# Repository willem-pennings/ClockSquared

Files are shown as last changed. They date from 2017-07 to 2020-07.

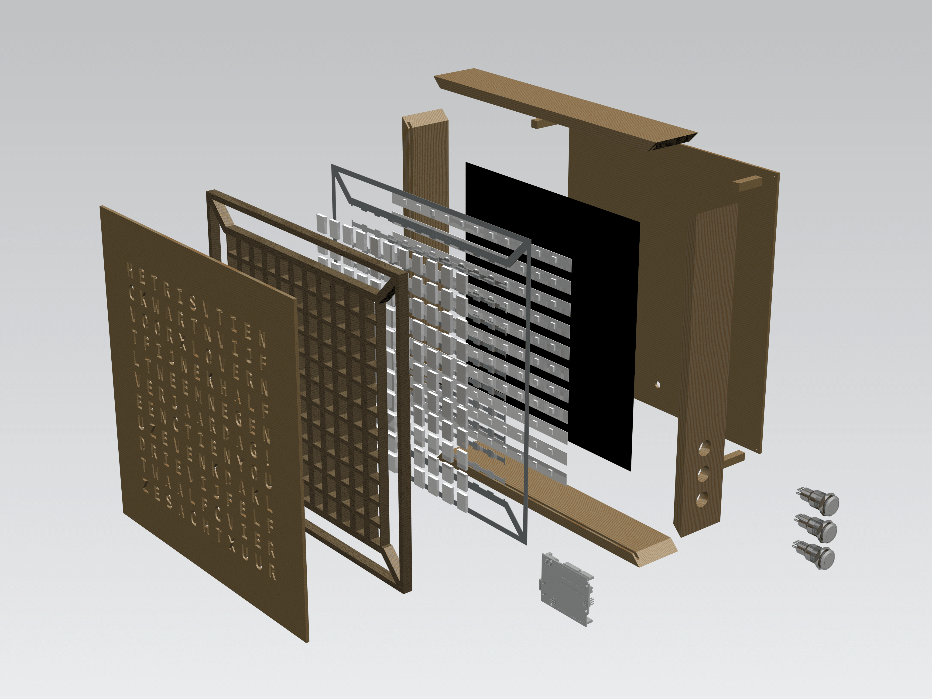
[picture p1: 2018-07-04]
assembly.png

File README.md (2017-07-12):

# Clocksquared
The Clocksquared word clock, which displays time and birthday messages

## Mechanical design files
The mechanical design files are stored inside the `Mechanical Design` folder. There's a main assembly file, `clocksquared_assy.prt`. Each of the individual components are stored in their own folder. Most files have a PDF file available with a technical drawing of the respective part.

## Source code
There are several source code files. Besides the main `wordclock.ino` file, there are other Arduino programs available for testing purposes or additional functionality (such as scrolling text).

## Other
A full build log of this clock is available at [my website](https://willemm.nl). You can also contact me through my website if you have any questions or remarks regarding this project.

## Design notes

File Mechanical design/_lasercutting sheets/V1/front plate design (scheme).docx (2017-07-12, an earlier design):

H | E | T | R | I | S | V | T | I | E | N
C | K | W | A | R | T | N | V | I | J | F
V | O | O | R | X | L | O | V | E | R | N
T | F | I | J | N | E | K | H | A | L | F
L | T | W | E | E | M | N | E | G | E | N
V | E | R | J | A | A | R | D | A | G | !
E | E | N | C | T | I | E | N | Y | O | U
B | Z | E | V | E | N | K | D | A | K | L
D | R | I | E | V | I | J | F | E | L | F
T | W | A | A | L | F | C | V | I | E | R
Z | E | S | A | C | H | T | X | U | U | R

# Word clock design (version 2.0) [Clocksquared]

- All Dutch time words (20, including “HET IS”);
- ‘Fijne verjaardag’;

Pixel number 1 (index 0) should align with top-left letter H.
Pixel number 121 (index 120) should align with bottom-right letter R.

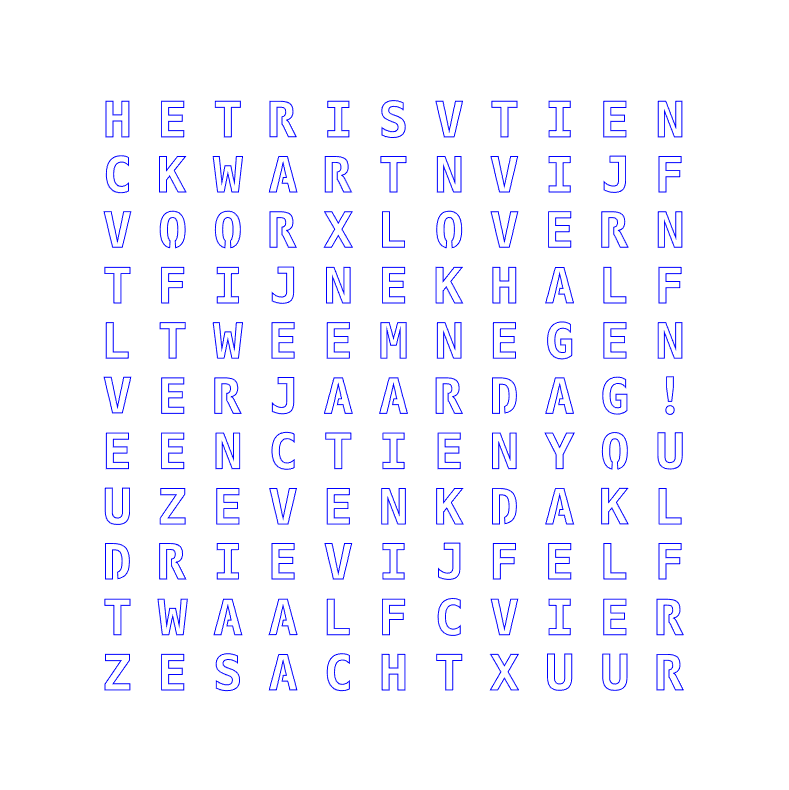
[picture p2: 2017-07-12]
letter layout - Dutch.png

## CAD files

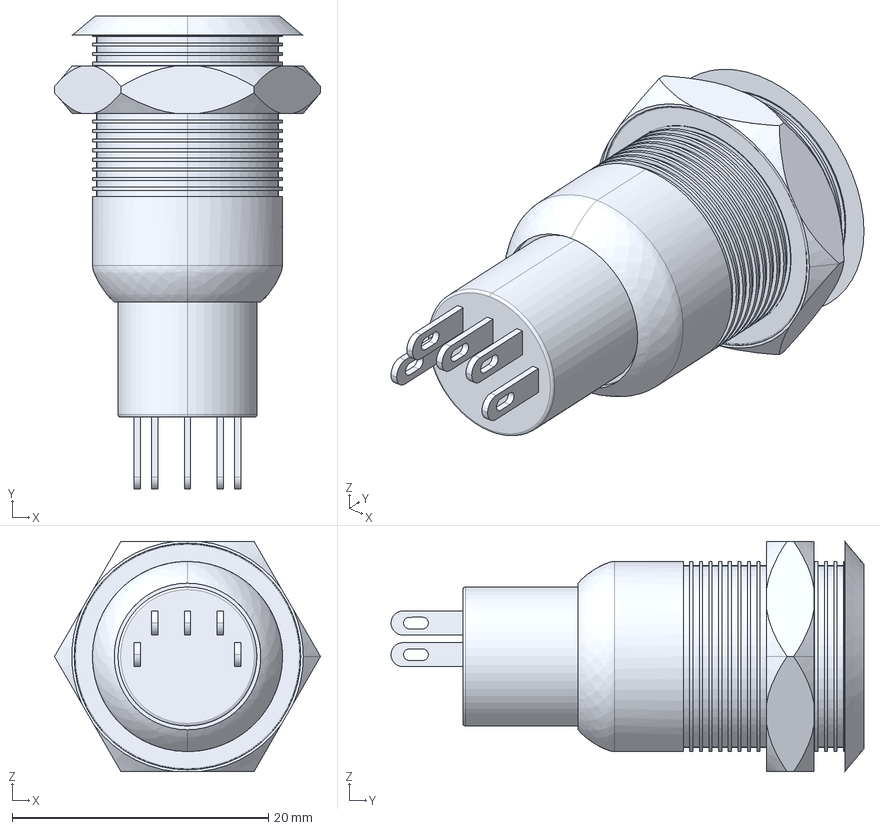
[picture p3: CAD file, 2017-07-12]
Mechanical design/components/pushbutton_16mm.stp
20.8 x 36.9 x 18.0 mm

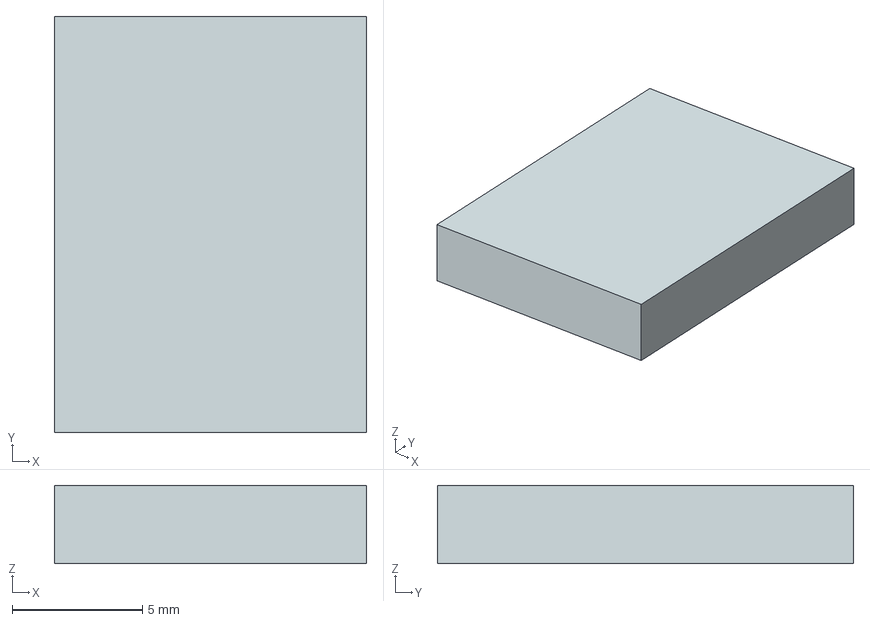
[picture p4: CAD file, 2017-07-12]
Mechanical design/diffuser/diffuser.stp
12.0 x 16.0 x 3.00 mm

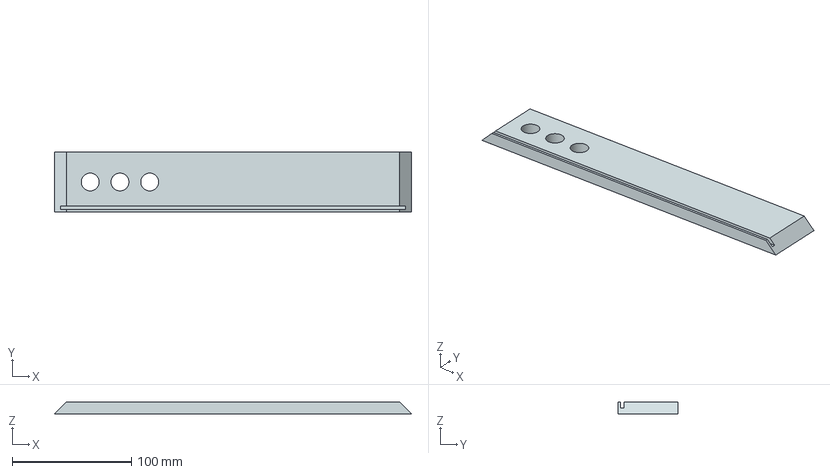
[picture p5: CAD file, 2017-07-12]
Mechanical design/frame_buttons/frame_buttons.stp
300.0 x 50.0 x 10.0 mm

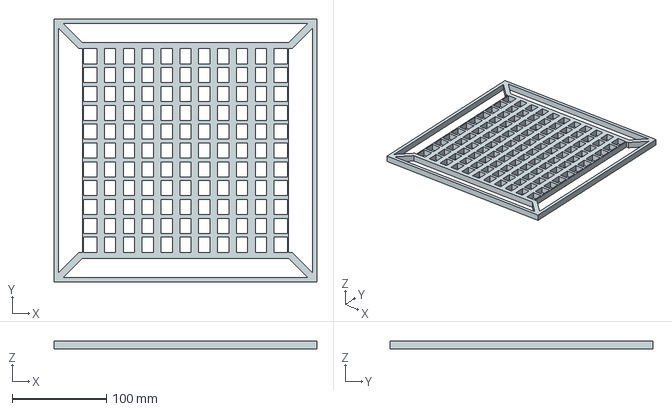
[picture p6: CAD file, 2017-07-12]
Mechanical design/grid/grid.stp
279.0 x 279.0 x 9.00 mm

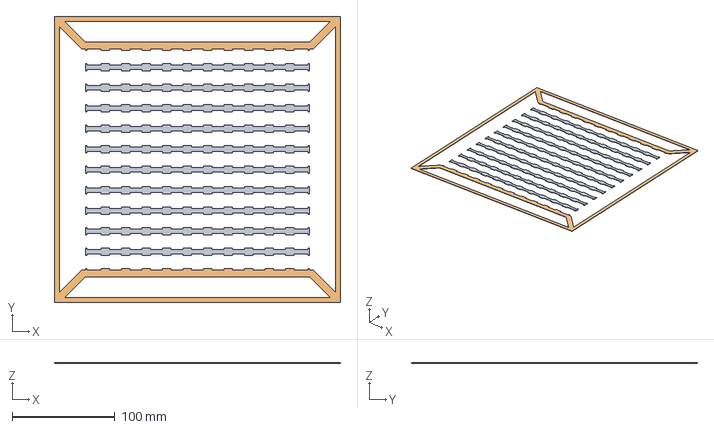
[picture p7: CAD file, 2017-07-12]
Mechanical design/grid_spacer/grid_spacer.stp
279.0 x 279.0 x 0.5 mm

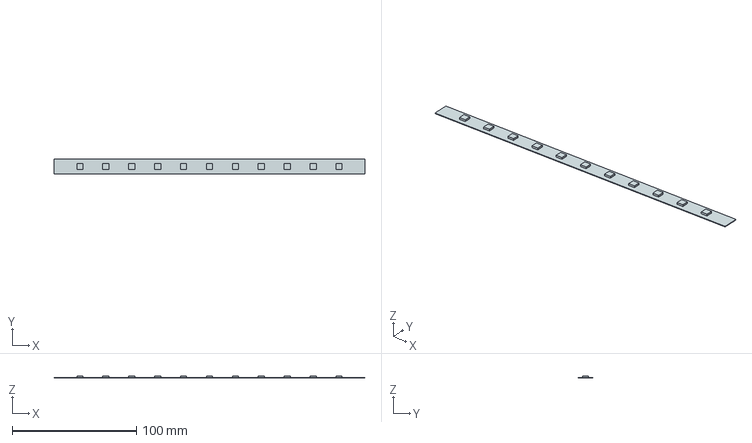
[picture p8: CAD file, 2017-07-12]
Mechanical design/ledstrip/ledstrip.stp
250.0 x 12.0 x 1.90 mm

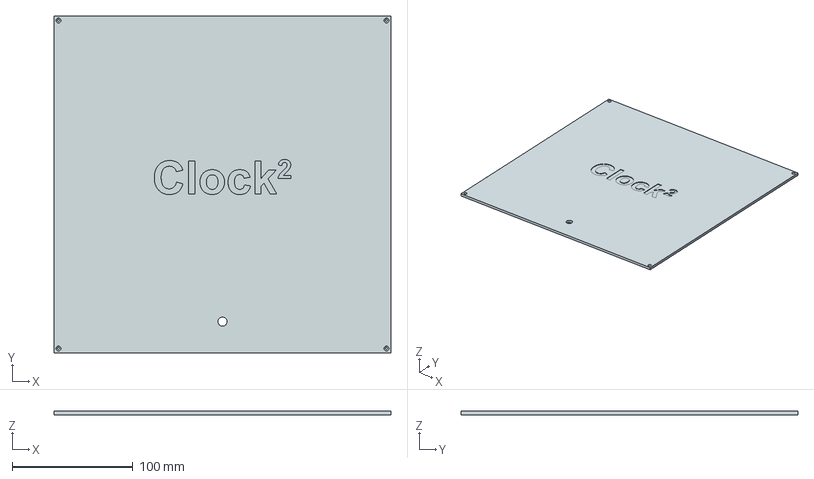
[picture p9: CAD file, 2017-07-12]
Mechanical design/sheet_back/sheet_back.stp
279.5 x 279.5 x 3.00 mm

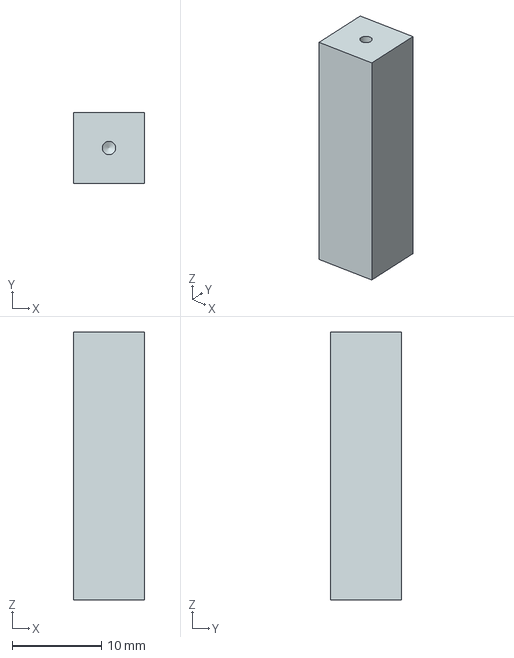
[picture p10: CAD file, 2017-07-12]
Mechanical design/standoff/standoff.stp
8.00 x 8.00 x 30.0 mm

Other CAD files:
Mechanical design/frame_regular/frame_regular.stp
Mechanical design/_lasercutting sheets/V1/clocksquared_lasercutting_laserbeest.dwg
Mechanical design/_lasercutting sheets/V1/clocksquared_grid.dwg
Mechanical design/_lasercutting sheets/V1/clocksquared_frontplate_standard.dwg
Mechanical design/clocksquared_assy.prt
Mechanical design/components/pushbutton_16mm.prt
Mechanical design/diffuser/diffuser.prt
Mechanical design/diffuser/diffuser_dwg.prt
Mechanical design/frame_buttons/frame_buttons.prt
Mechanical design/frame_buttons/frame_buttons_dwg.prt
Mechanical design/frame_regular/frame_regular.prt
Mechanical design/frame_regular/frame_regular_dwg.prt
Mechanical design/grid/grid.prt
Mechanical design/grid/grid_dwg.prt
Mechanical design/grid_spacer/grid_spacer.prt
Mechanical design/grid_spacer/grid_spacer_dwg.prt
Mechanical design/ledstrip/ledstrip.prt
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

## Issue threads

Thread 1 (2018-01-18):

Poor documentation and vital missing parts.

tretron, 2018-01-18:
The documentation of this project is poor, I had to rework most of the dementions to make it work. however the worst part is the code, nothing gets explained. using the serial monitor resets the time...sometimes. and it is not clear how to select the date. I have added the following:

//setTime(1516265031); // set system time however uncomment after time is set

in order to temporarily set the time to EPOCH time. and after that manually adjust the time. Please adjust the code so it's easier to read and profide some documentation on how to adjust the time to current date via epoch time. or allow the serial monitor to set a EPOCH time.

willem-pennings, 2018-02-10:
- I do not understand what you mean by 'reworking dementions'.

- This sketch does not include any code to set the time of a RTC by purpose, since there is no easy way of configuring time using the button interface. This should be done using a separate DS3231-compatible sketch and only needs to be done again once the RTC battery runs out (this takes several years). Many sketches to configure time on a DS3231 RTC are available online.

- You mention that 'nothing gets explained'. The code is filled with comments which should help you understand it. If there still are parts that you do not understand after careful evaluation, please let me know such that I can provide some additional comments. It should also be noted that all of the `displayTime ` function is based on Dutch language - the words used to indicate 13:20 are very different in Dutch than in English. This might be hard to comprehend for someone who does not speak the language.

Closed 2018-02-24.

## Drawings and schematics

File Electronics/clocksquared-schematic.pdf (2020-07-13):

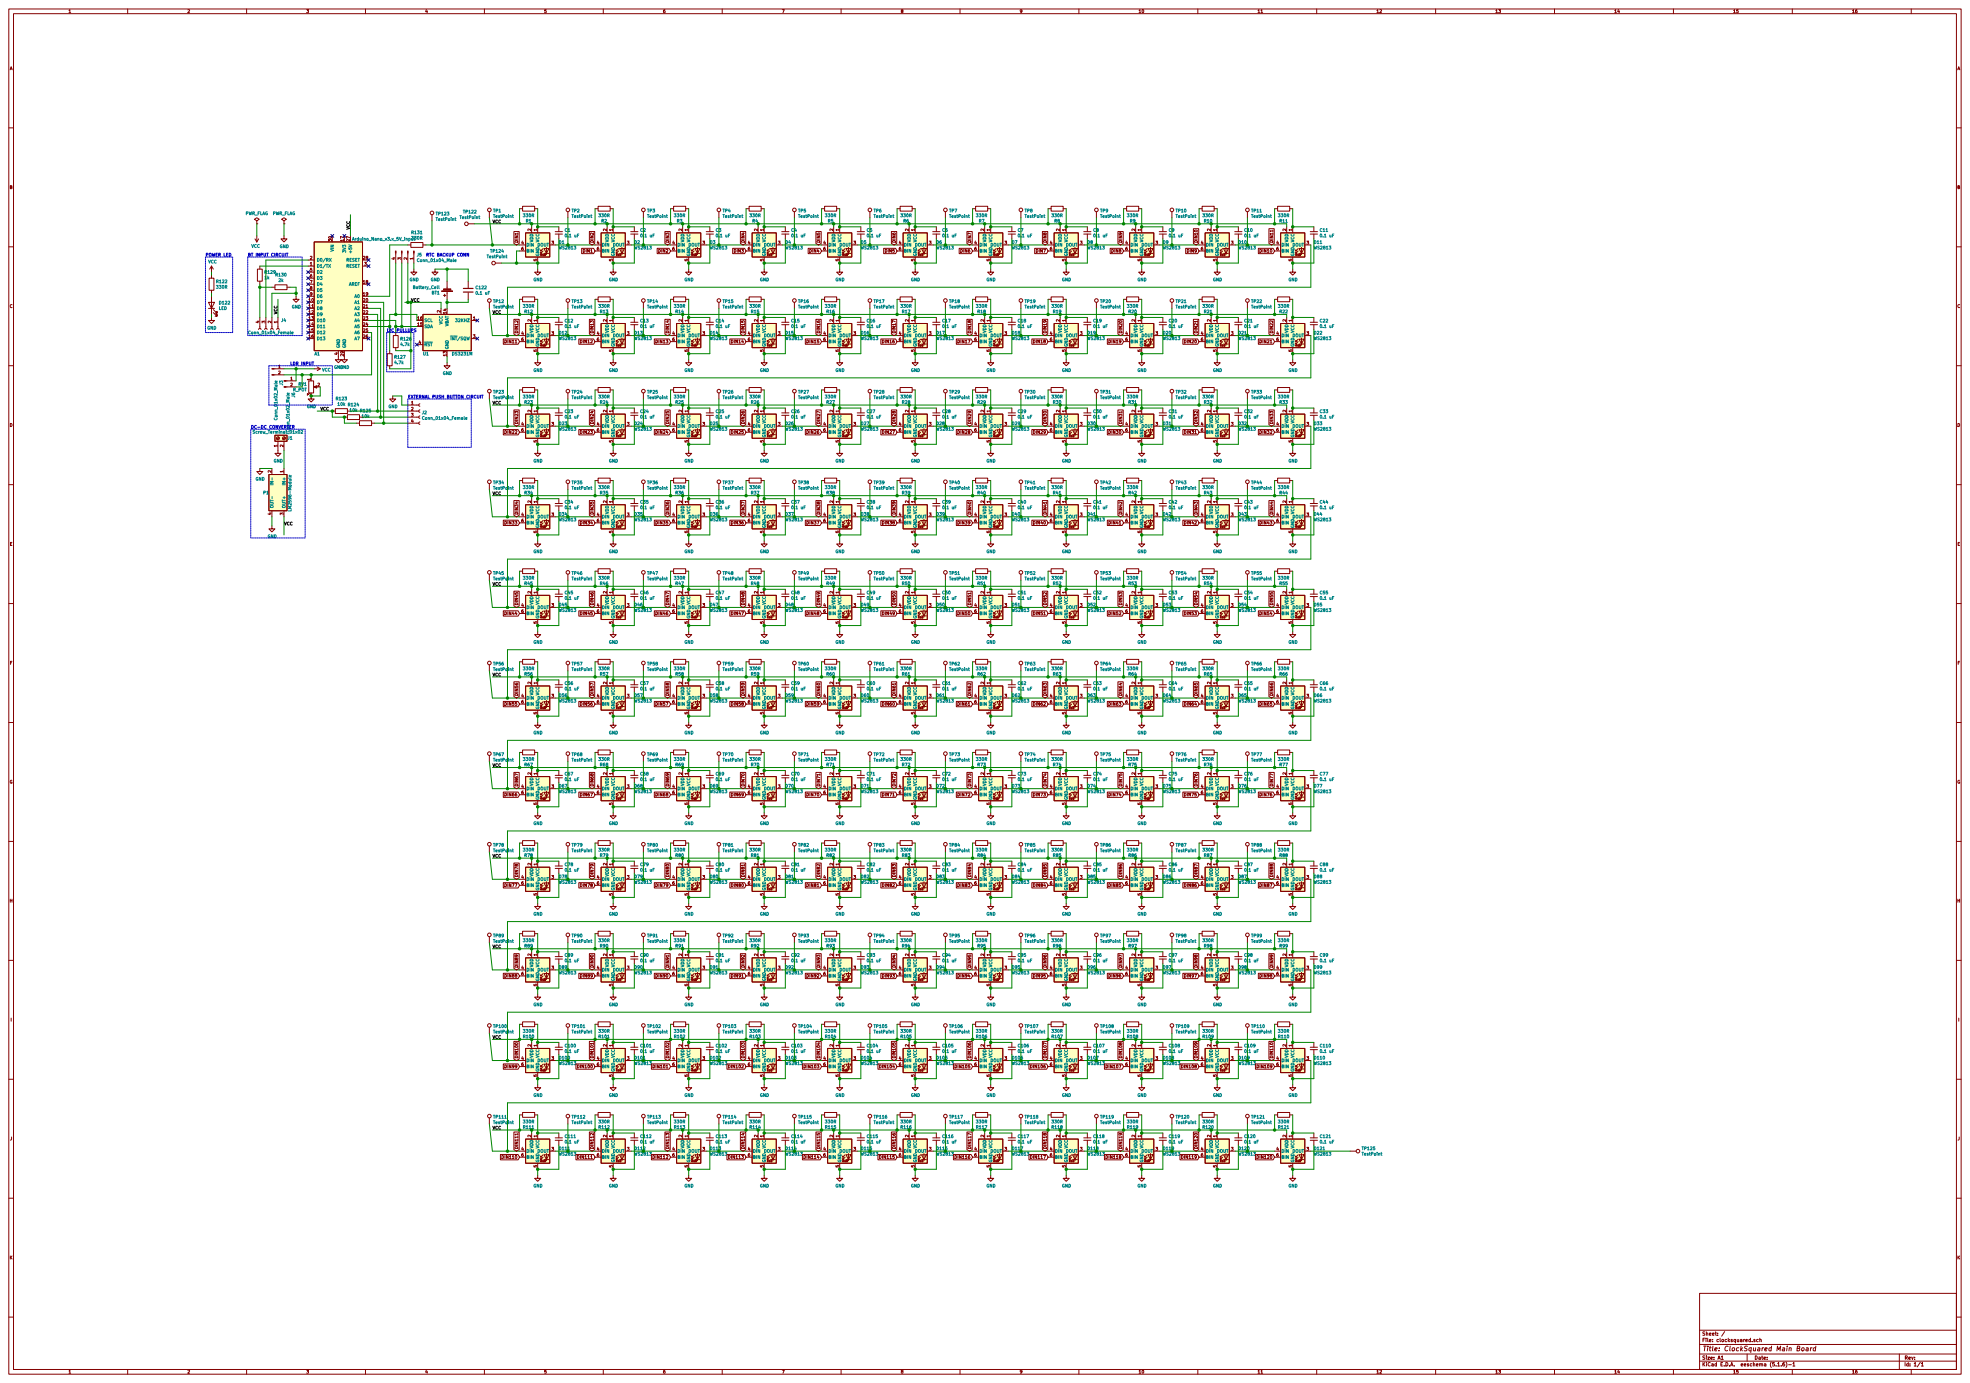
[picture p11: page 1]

VCC
LDR INPUT BT INPUT CIRCUIT

1 VDD
TP66 TestPoint TP65 TestPoint TP64 TestPoint TP63 TestPoint TP62 TestPoint RGB VCC

TP77 TestPoint TP76 TestPoint TP75 TestPoint TP74 TestPoint TP73 TestPoint TP72 TestPoint TP71 TestPoint TP70 TestPoint TP69 TestPoint TP68 TestPoint

TP87 TestPoint TP86 TestPoint TP85 TestPoint TP84 TestPoint TP83 TestPoint TP82 TestPoint TP81 TestPoint

TP96 TestPoint TP95 TestPoint TP94 TestPoint TP93 TestPoint TP92 TestPoint TP91 TestPoint TP90 TestPoint

5 BIN 6 D114 WS2813TP104 TestPoint TP103 TestPoint TP107 TestPoint GND

File: clocksquared.sch Sheet: /
Id: 1/1 Title: ClockSquared Main Board

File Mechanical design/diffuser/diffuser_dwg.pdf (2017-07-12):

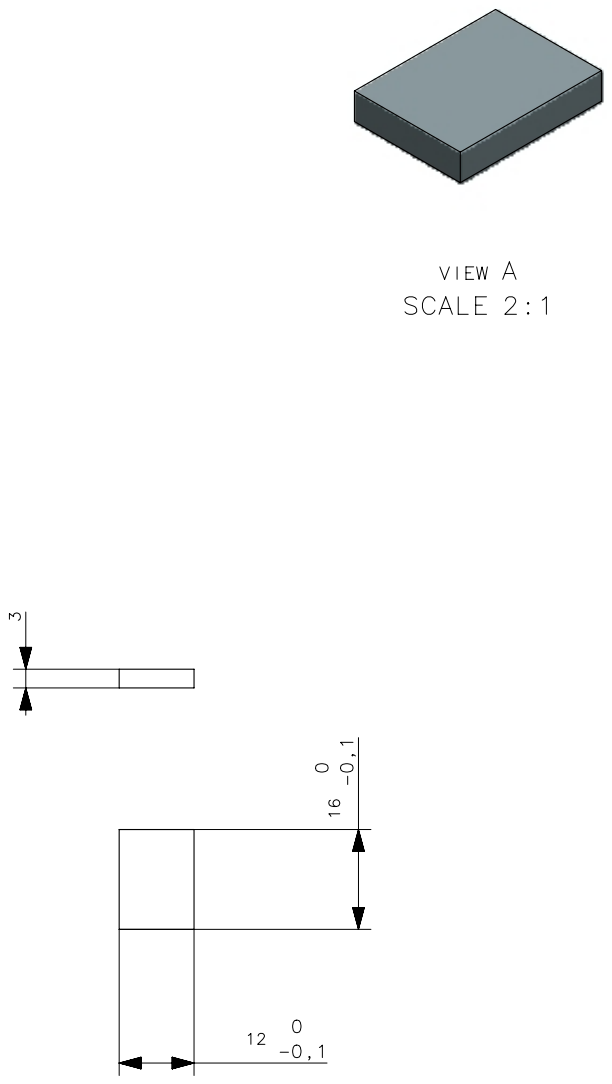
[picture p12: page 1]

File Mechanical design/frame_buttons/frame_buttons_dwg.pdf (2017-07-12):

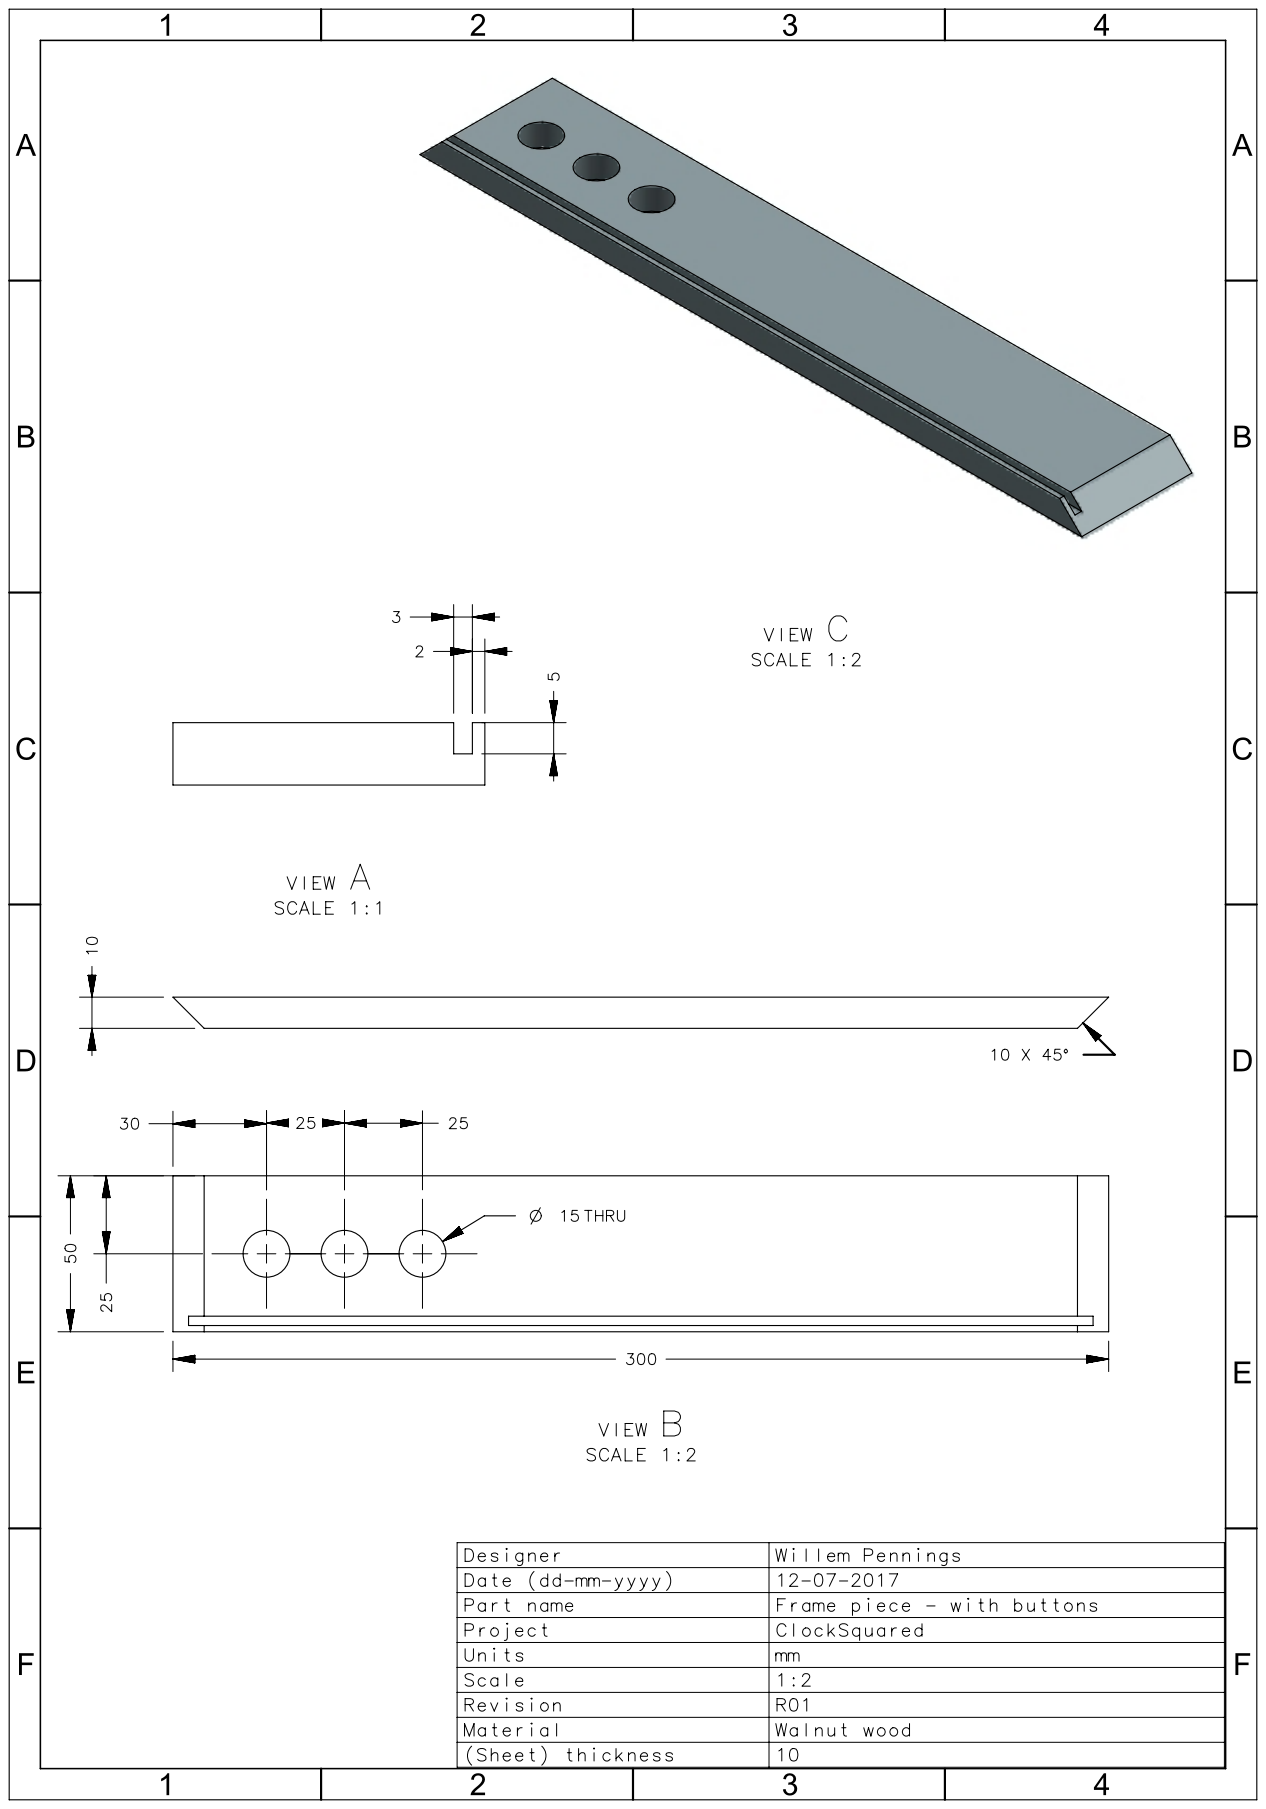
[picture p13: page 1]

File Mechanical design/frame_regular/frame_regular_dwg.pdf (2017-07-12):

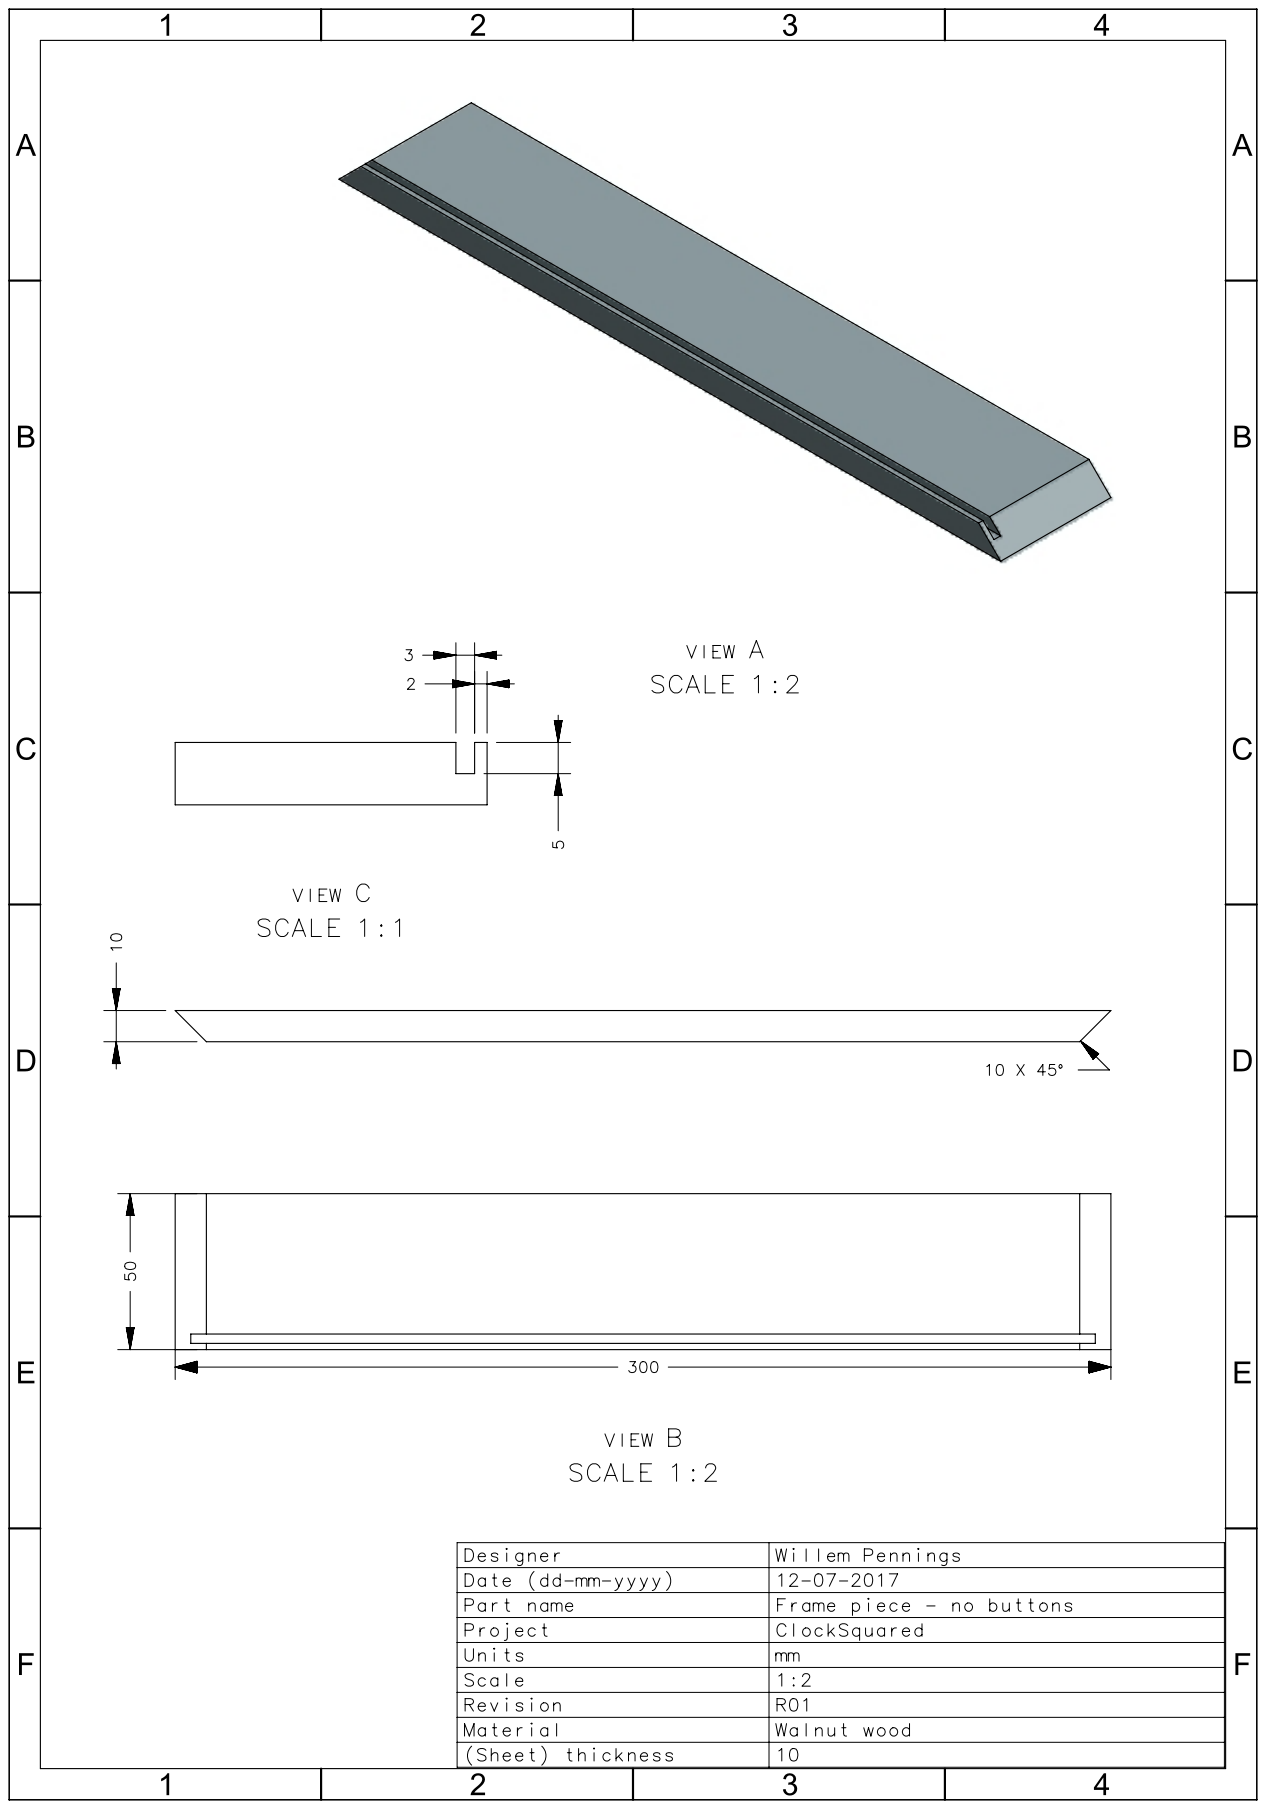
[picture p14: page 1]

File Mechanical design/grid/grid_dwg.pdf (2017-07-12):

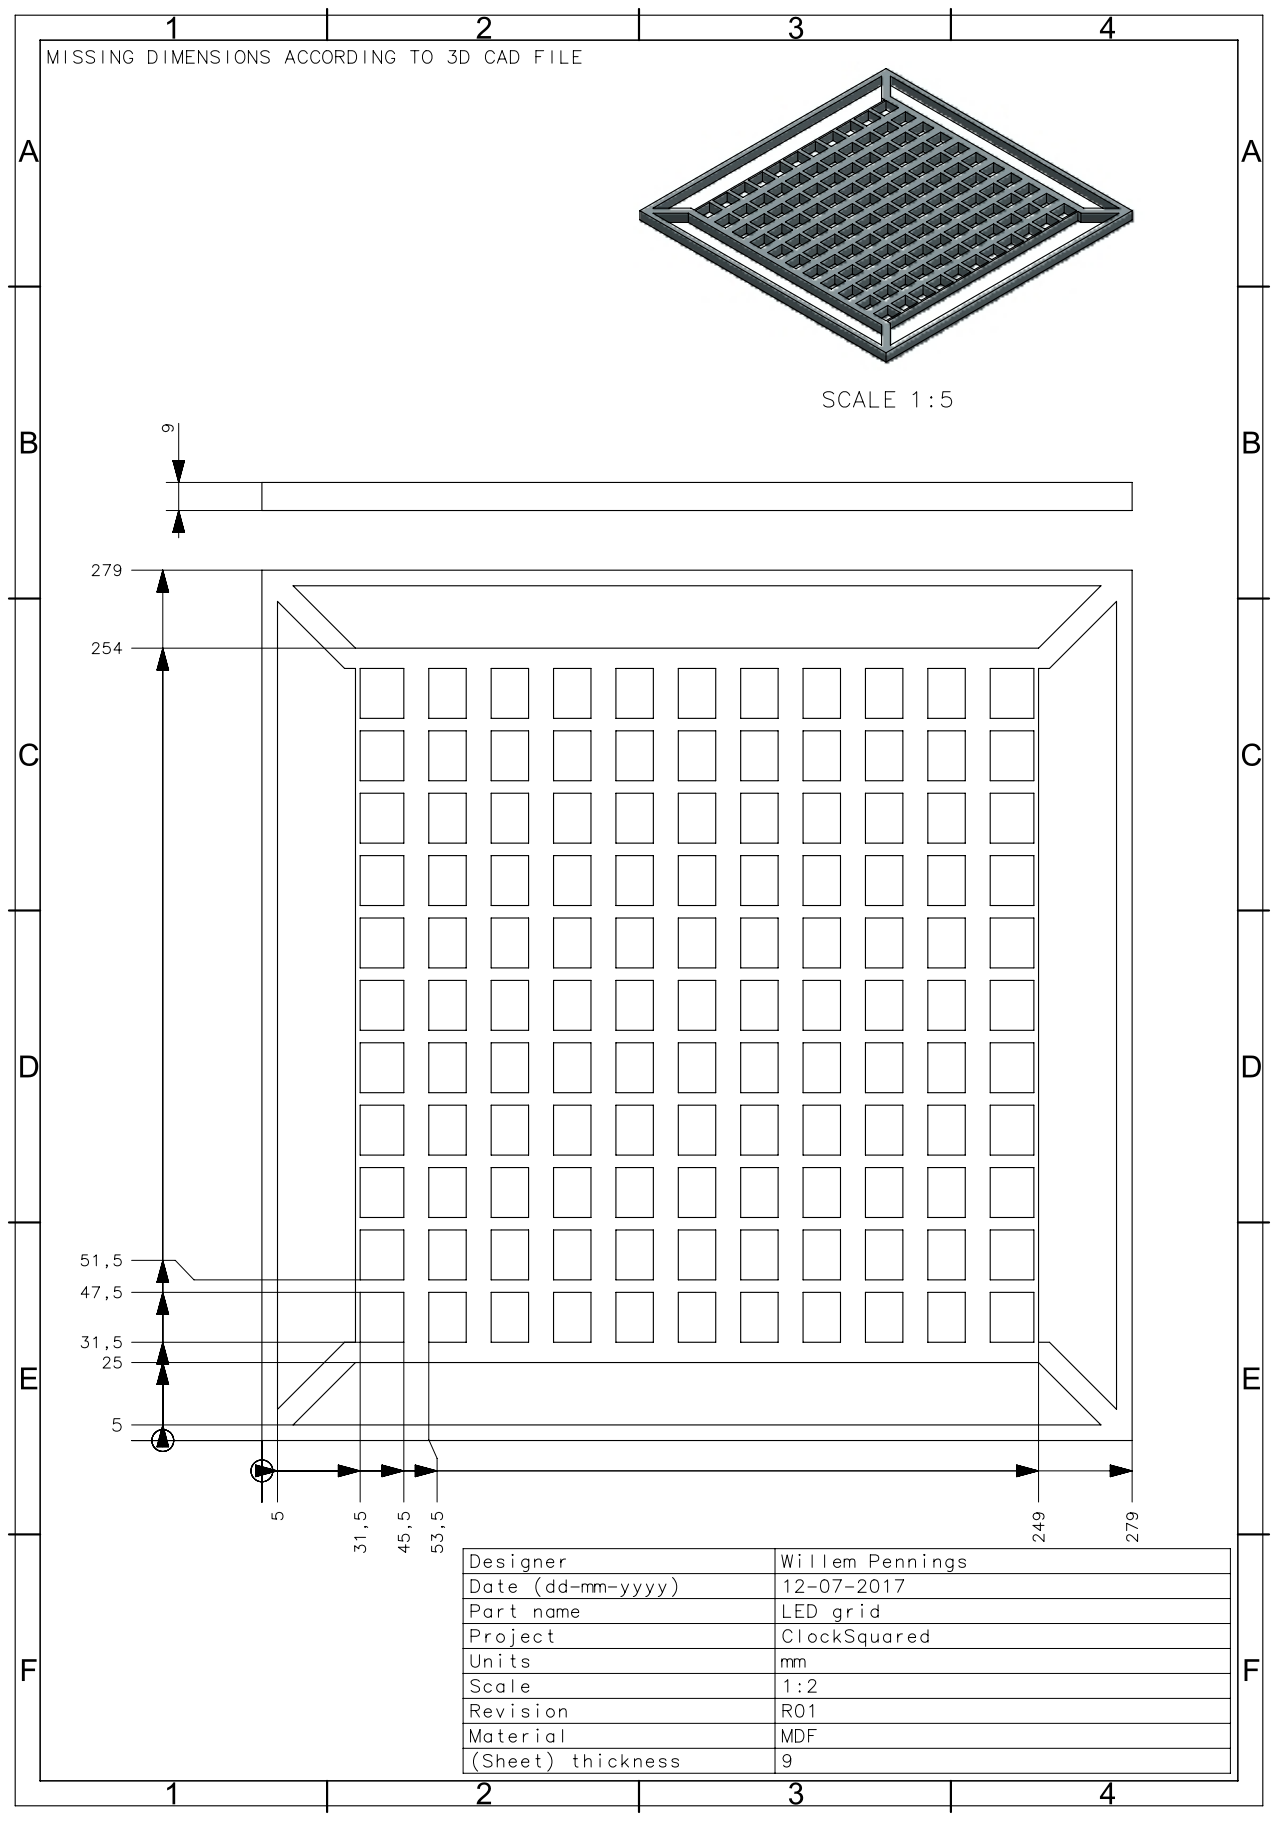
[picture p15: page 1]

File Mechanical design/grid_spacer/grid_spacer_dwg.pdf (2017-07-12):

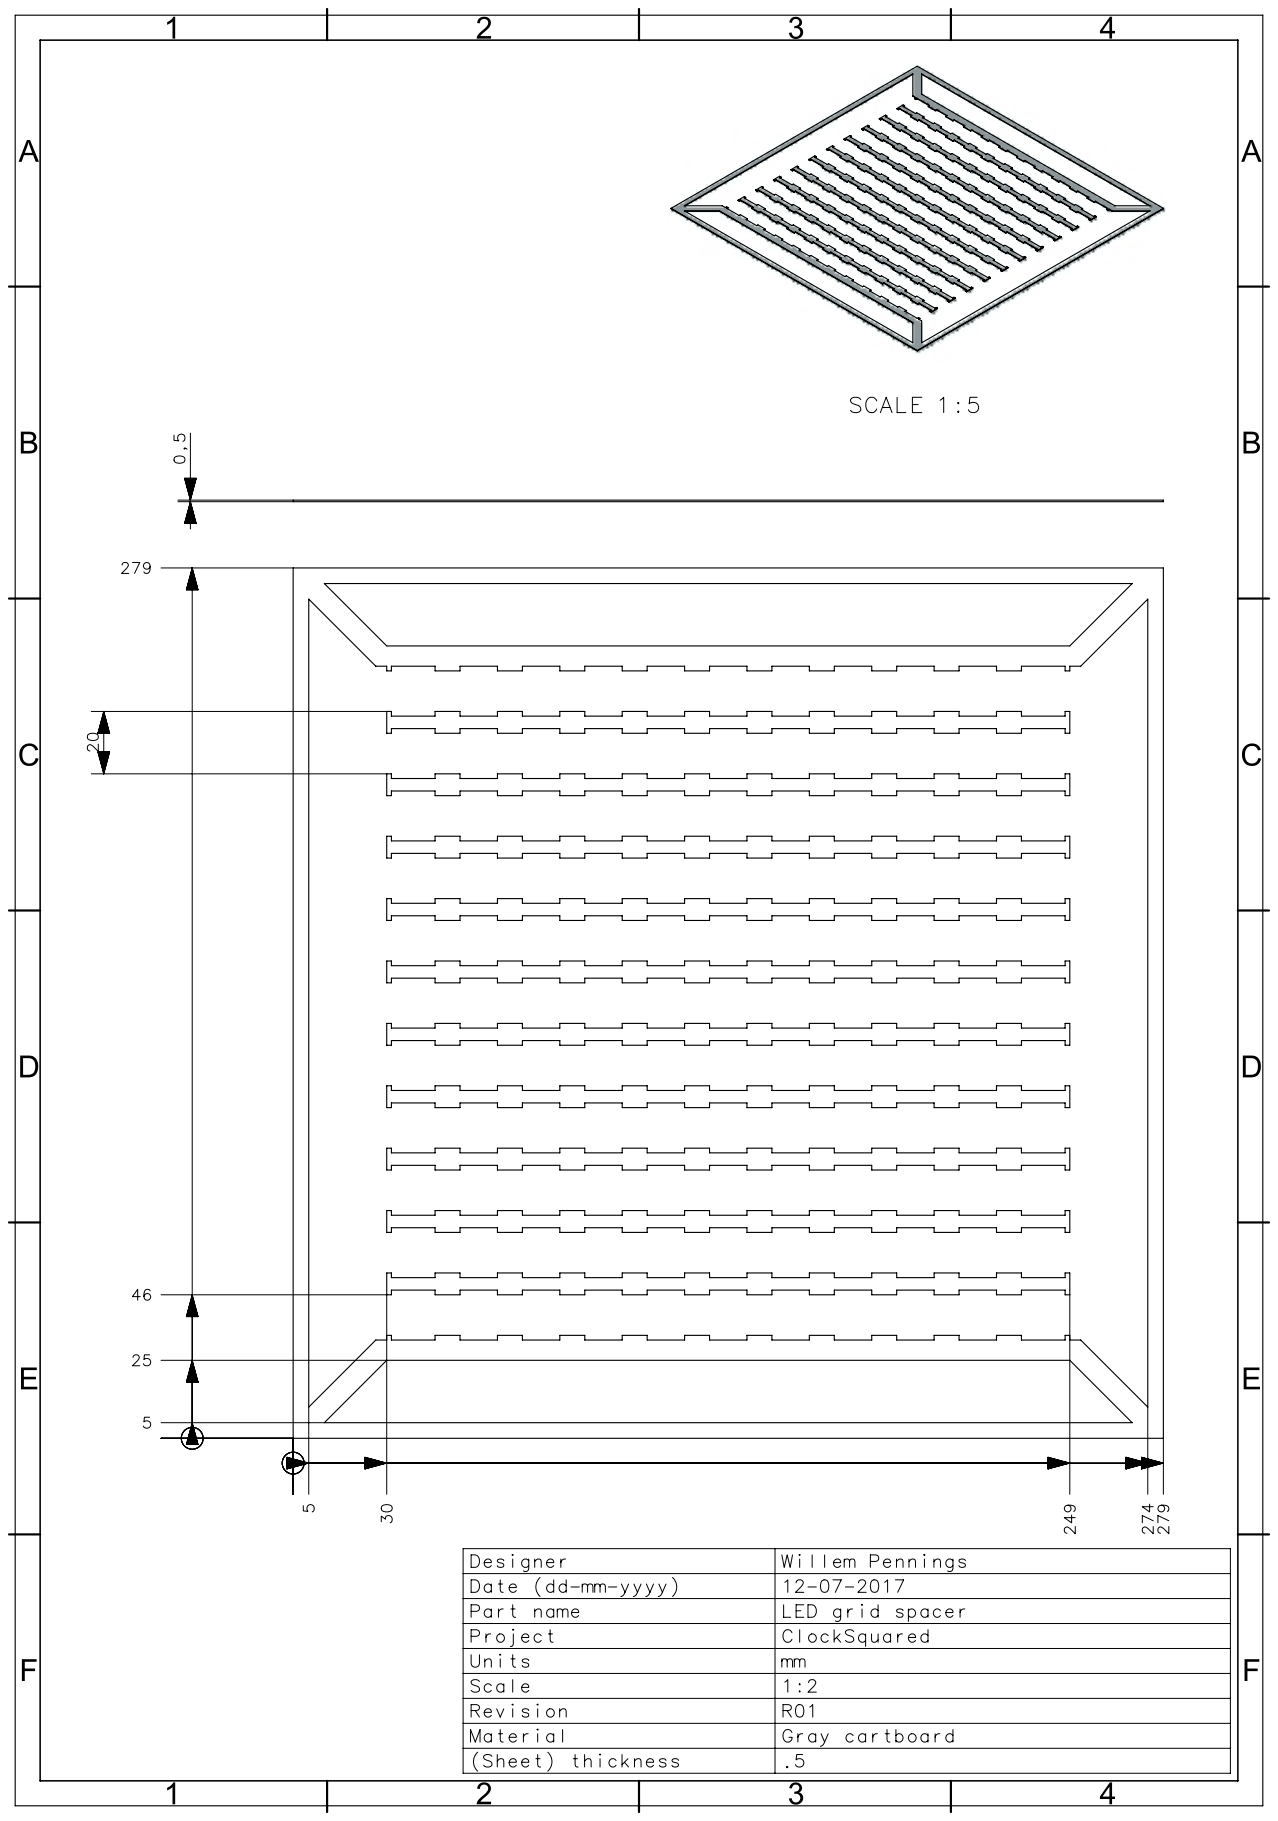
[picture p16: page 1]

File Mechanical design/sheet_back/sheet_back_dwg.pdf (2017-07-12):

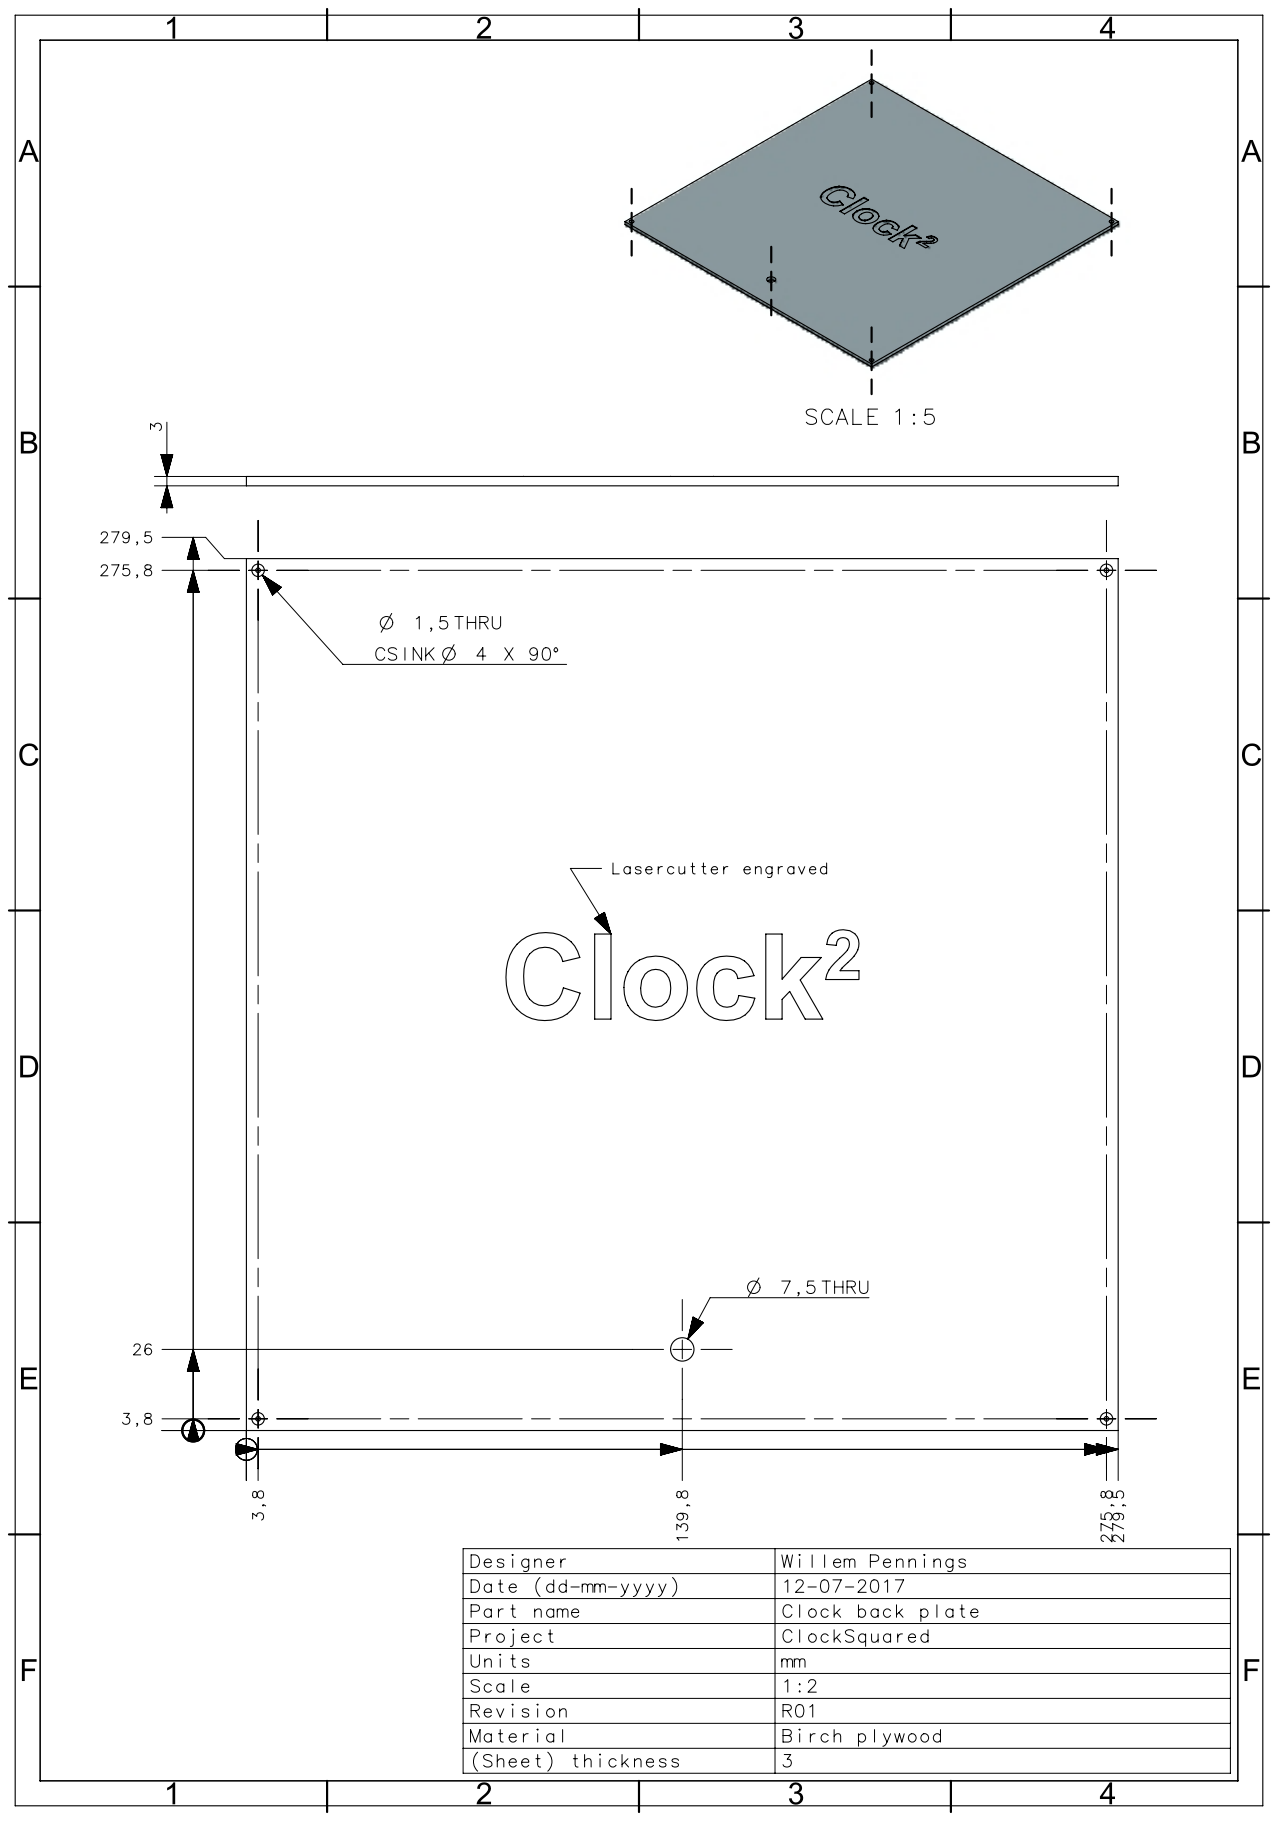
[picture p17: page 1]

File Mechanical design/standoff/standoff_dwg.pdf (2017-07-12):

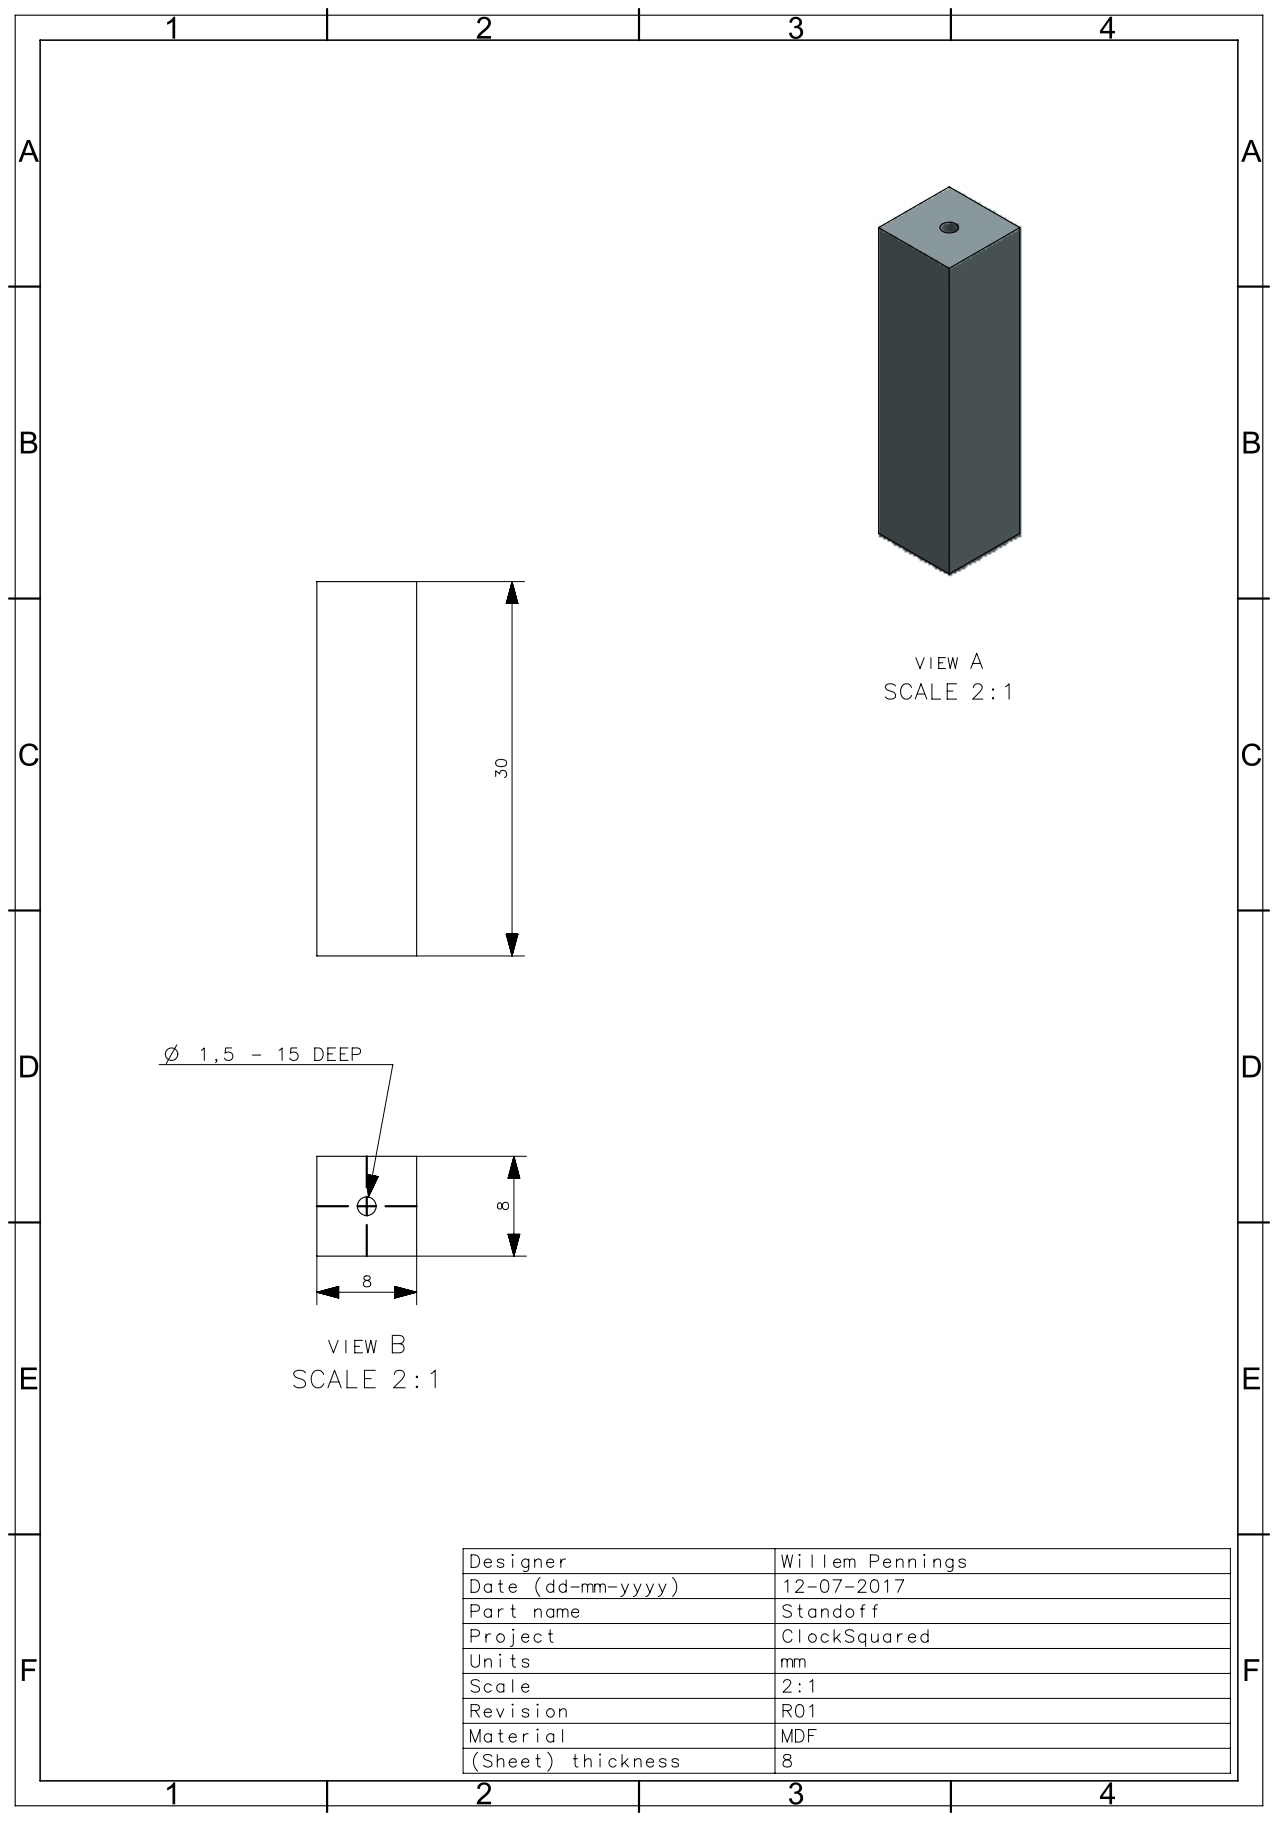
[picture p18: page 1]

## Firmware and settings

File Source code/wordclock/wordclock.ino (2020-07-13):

/* ClockSquared by Willem Pennings
 * A WS2812B-based word clock with birthday feature
 * Copyright (C) 2017-2019 Willem Pennings (willemm.nl)
 * The FastLED and RTClib library are required to compile this sketch!
 */

/* Libraries */
#include <Wire.h>
#include <EEPROM.h>
#include "FastLED.h"
#include "RTClib.h"

RTC_DS3231 rtc;
RTC_Millis softrtc;
FASTLED_USING_NAMESPACE

const bool mirrorDisplay    = true;
const bool boustrofedon     = true;
                        
/* LED strip and grid definitions */
#define LED_TYPE              WS2812B     // [-] - LED strip model
#define COLOR_ORDER           GRB         // [-] - LED strip color order
const uint8_t numLeds       = 121;        // [-] - Number of LEDS
const uint8_t dataPin       = A0;         // [-] - LED data pin

CRGB leds[numLeds];
CRGB leds_p[numLeds];

/* Input pin definitions */
const uint8_t buttonPins[3] = {A1,A2,A3};  // [-] - Button pins
const uint8_t buttonLedPin  = 12;          // Button LED power pin

/* HSV colour variables */
uint8_t hue                 = 0;           // [-] - Red as standard hue value.
uint8_t sat                 = 0;           // [-] - 0 saturation for white colour as default.
uint8_t val                 = 255;         // [-] - Full brightness is standard value.

/* General variables */
uint16_t interval           = 1000;       // [ms] - General time interval variable
uint8_t brightness          = 128;        // [-] - LED strip global brightness on a scale of 0 to 255
unsigned long updateTime    = 0;          // [ms] - Time at which the last time update was done
bool index[20]              = {0,0,0,0,0,0,0,0,0,0,0,0,0,0,0,0,0,0,0,0};
uint8_t i,j,k               = 0;          // [-] - General purpose indexing variables
bool maintenanceMode        = false;      // [-] - Maintenance mode toggle

/* Colour variables */
const uint8_t colours[8][3] PROGMEM = {{  0,  0,255},  // white
                                       {  0,255,255},  // red
                                       { 30,255,255},  // orange
                                       { 43,255,255},  // yellow
                                       { 85,255,255},  // green
                                       {170,255,255},  // blue
                                       {213,255,255},  // magenta
                                       {248,255,224}}; // pink

uint8_t colourIndex        = 0;
bool birthdayMode          = false;
bool manualBirthdayMode    = false;
bool softRTC               = false;

/* Birthday LED positions */
const uint8_t birthdayPos[16] PROGMEM = {34,35,36,37,38,55,56,57,58,59,60,61,62,63,64,65};

// Bitmap font locations
const uint8_t posL[35] PROGMEM = {22,23,24,25,26,33,34,35,36,37,44,45,46,47,48,55,56,57,58,59,66,67,68,69,70,77,78,79,80,81,88,89,90,91,92};
const uint8_t posR[35] PROGMEM = {28,29,30,31,32,39,40,41,42,43,50,51,52,53,54,61,62,63,64,65,72,73,74,75,76,83,84,85,86,87,94,95,96,97,98};
                          
/* 5x7 bitmap number font */
const uint8_t font5x7[10][35] PROGMEM = {{0,1,1,1,0,1,0,0,0,1,1,0,0,1,1,1,0,1,0,1,1,1,0,0,1,1,0,0,0,1,0,1,1,1,0},  // 0
                                         {0,1,1,0,0,1,0,1,0,0,0,0,1,0,0,0,0,1,0,0,0,0,1,0,0,0,0,1,0,0,1,1,1,1,1},  // 1
                                         {0,1,1,1,0,1,0,0,0,1,0,0,0,1,0,0,0,1,0,0,0,1,0,0,0,1,0,0,0,0,1,1,1,1,1},  // 2
                                         {0,1,1,1,0,1,0,0,0,1,0,0,0,0,1,0,1,1,1,0,0,0,0,0,1,1,0,0,0,1,0,1,1,1,0},  // 3
                                         {0,0,0,1,0,0,0,1,1,0,0,1,0,1,0,1,0,0,1,0,1,1,1,1,1,0,0,0,1,0,0,0,0,1,0},  // 4
                                         {1,1,1,1,1,1,0,0,0,0,1,1,1,1,0,0,0,0,0,1,0,0,0,0,1,1,0,0,0,1,0,1,1,1,0},  // 5
                                         {0,1,1,1,0,1,0,0,0,1,1,0,0,0,0,1,1,1,1,0,1,0,0,0,1,1,0,0,0,1,0,1,1,1,0},  // 6
                                         {1,1,1,1,1,0,0,0,0,1,0,0,0,1,0,0,0,1,0,0,0,1,0,0,0,0,1,0,0,0,0,1,0,0,0},  // 7
                                         {0,1,1,1,0,1,0,0,0,1,1,0,0,0,1,0,1,1,1,0,1,0,0,0,1,1,0,0,0,1,0,1,1,1,0},  // 8
                                         {0,1,1,1,0,1,0,0,0,1,1,0,0,0,1,0,1,1,1,1,0,0,0,0,1,1,0,0,0,1,0,1,1,1,0}}; // 9

// Amount of birthdays that can be stored in EEPROM
const uint8_t nBirthdays = 20;

// Debounce condition for switching between maintenance mode and regular mode
unsigned long switchTime = 0;

// Timer for AM PM indicator display
unsigned long APTime = 0;

void setup() { 
  // Clear display at startup and provide time for hardware initialization
  delay(1000);
  FastLED.clear();
  
  // Initialize communications
  Serial.begin(115200);
  Wire.begin();

  // Initialize pins
  for(i = 0; i < 3; i++) {
    pinMode(buttonPins[i], INPUT);
  }
  
  pinMode(buttonLedPin, OUTPUT);
  digitalWrite(buttonLedPin, HIGH);

  // Initialize LED strip
  FastLED.addLeds<LED_TYPE, dataPin, COLOR_ORDER>(leds_p, numLeds).setCorrection(TypicalLEDStrip);
  FastLED.setBrightness(brightness);

  if(rtc.lostPower()) {
    Serial.println(F("Could not find RTC or RTC lost power. Falling back to softrtc timekeeping..."));
    softrtc.begin(DateTime(2019, 1, 1, 0, 0, 0));
    rtc.adjust(DateTime(2019, 1, 1, 0, 0, 0));
    Serial.println(F("Datetime has been set to January 1, 2019, 12AM (midnight)."));
    softRTC = true;

    // Blink center LED three times in red to indicate RTC failure
    for(i = 0; i < 3; i++) {
      leds_p[60] = CRGB::Red;
      FastLED.show();
      delay(500);
      leds_p[60] = CRGB::Black;
      FastLED.show();
      delay(500);
    }
  }
  
  // Startup animation in RGB sequence to verify correctness of software colour order
  leds_p[60] = CRGB::Red;
  for(i = 0; i < 25; i++) {
    leds_p[60].fadeToBlackBy(26);
    FastLED.show();
    delay(20);
  }
  leds_p[60] = CRGB::Green;
  for(i = 0; i < 25; i++) {
    leds_p[60].fadeToBlackBy(26);
    FastLED.show();
    delay(20);
  }
  leds_p[60] = CRGB::Blue;
  for(i = 0; i < 25; i++) {
    leds_p[60].fadeToBlackBy(26);
    FastLED.show();
    delay(20);
  }
  leds_p[60] = CRGB::White;
  for(j = 0; j < 50; j++) {
    leds_p[60].fadeToBlackBy(26);
    FastLED.show();
    delay(10);
  }
  
  FastLED.clear();

  // Read previous screen colour from EEPROM
  if(EEPROM.read(2*nBirthdays) == 255) {
    colourIndex = 0;
  } else {
    colourIndex = EEPROM.read(2*nBirthdays);
  }
  hue = pgm_read_byte(&(colours[colourIndex][0]));
  sat = pgm_read_byte(&(colours[colourIndex][1]));
  val = pgm_read_byte(&(colours[colourIndex][2]));

  // Display system time on screen
  displayTime(hue, sat, val);

  // Check if the birthday message should be enabled
  checkBirthdays();
}

void loop() {
  if(!maintenanceMode) {
    // Timekeeping (refresh every minute)
    if(second() == 0 && (millis() - updateTime > interval)) {
      displayTime(hue, sat, val);
      updateTime = millis();
    }
  
    // Wipe birthday message at midnight and check for new birthdays
    if(hour() == 0 && minute() == 0 && second() == 0) {
      // Disable manual birthday mode if it was enabled
      if(manualBirthdayMode) {
        manualBirthdayMode = false;
      }
      
      if(birthdayMode) {
        for(i = 0; i < 16; i++) {
          leds[pgm_read_byte(&(birthdayPos[i]))] = CRGB::Black;
        }
      }

      // Check if there's a new birthday today
      checkBirthdays();
    }

    // Display birthday message if birthdayMode is enabled
    birthdays();
  
    // Check buttons
    buttons();
  } else {
    // Maintenance mode: set current date and birthdays
    setDateBirthdays();
  }

  // Check if AM/PM indicator should be shown (only when changing time)
  AMPMIndicator();

  // Refresh display
  printScreen(mirrorDisplay, boustrofedon);
}

// AM-PM indicator while changing time
void AMPMIndicator() {
  if(millis() - APTime < 2000) {
    if(hour() >= 12) {
      leds[3] = CRGB::Blue;
    } else {
      leds[3] = CRGB::Red;
    }
  } else {
    leds[3] = CRGB::Black;
  }
}

// Colour changing code
void changeColour() {
  if(colourIndex == 7) {
    colourIndex = 0;
  } else {
    colourIndex++;
  }

  hue = pgm_read_byte(&(colours[colourIndex][0]));
  sat = pgm_read_byte(&(colours[colourIndex][1]));
  val = pgm_read_byte(&(colours[colourIndex][2]));

  displayTime(hue, sat, val);

  // Write new colour value to EEPROM
  EEPROM.update(2*nBirthdays, colourIndex);
  
  Serial.println(F("Button 1 - Text colour changed."));
}

// Change screen brightness
void changeBrightness() {
  static bool incrementing = false;
  
  if(brightness == 128) {
    incrementing = false;
  } else
  if(brightness == 0) {
    incrementing = true;
  }
  
  if(incrementing) {
    brightness++;

    if(brightness == 32) {
      digitalWrite(buttonLedPin, HIGH);
      Serial.println(F("Button LEDs enabled."));
    }
  } else {
    brightness--;

    if(brightness == 32) {
      digitalWrite(buttonLedPin, LOW);
      Serial.println(F("Button LEDs disabled."));
    }
  }

  FastLED.setBrightness(brightness);
  
  Serial.print(F("Button 1 + 2 - brightness changed (")); Serial.print(brightness); Serial.println(F(")."));
}

// Increment time to the next 5-minute indicator
void incrementTime() {
  if(!softRTC) {
    DateTime now = rtc.now();
    int adjustment = -((5 + (minute() % 5)) * 60 + second()) + 600;
    rtc.adjust(now + adjustment);
  } else {
    DateTime now = softrtc.now();
    int adjustment = -((5 + (minute() % 5)) * 60 + second()) + 600;
    softrtc.adjust(now + adjustment);
    rtc.adjust(now + adjustment);
  }

  displayTime(hue, sat, val);
  checkBirthdays();
  APTime = millis();
  Serial.println(F("Button 2 - time incremented."));
}

// Decrement time to the previous 5-minute indicator
void decrementTime() {
  if(!softRTC) {
    DateTime now = rtc.now();
    int adjustment = -((5 + (minute() % 5)) * 60 + second());
    rtc.adjust(now + adjustment);
  } else {
    DateTime now = softrtc.now();
    int adjustment = -((5 + (minute() % 5)) * 60 + second());
    softrtc.adjust(now + adjustment);
    rtc.adjust(now + adjustment);
  }

  displayTime(hue, sat, val);
  checkBirthdays();
  APTime = millis();
  Serial.println(F("Button 3 - time decremented."));
}

void buttons() {
  int readings[3];
  static bool lastReadings[3];
  static unsigned long buttonTime, cTime, iTime, dTime, bTime, vTime, sTime;

  static int debounceTime = 200;

  // Get and process readings
  if(analogRead(buttonPins[0]) < 100) {readings[0] = true;} else {readings[0] = false;}
  if(analogRead(buttonPins[1]) < 100) {readings[1] = true;} else {readings[1] = false;}
  if(analogRead(buttonPins[2]) < 100) {readings[2] = true;} else {readings[2] = false;}

  // Check if button state has changed w.r.t. last loop
  for(i = 0; i < 3; i++) {
    if(readings[i] != lastReadings[i]) {
      // Register time at which buttons were pressed
      buttonTime = millis();
    }
  }

  // Debounce conditions
  if(millis() - buttonTime > debounceTime) {
    // Button 1 press
    if(readings[0] == 1 && readings[1] == 0 && readings[2] == 0 && (millis() - cTime > 500)) {
      changeColour();
      cTime = millis();
    } else
    // Button 2 press
    if(readings[0] == 0 && readings[1] == 1 && readings[2] == 0 && (millis() - iTime > 500)) {
      incrementTime();
      iTime = millis();
    } else
    // Button 3 press
    if(readings[0] == 0 && readings[1] == 0 && readings[2] == 1 && (millis() - dTime > 500)) {
      decrementTime();
      dTime = millis();
    } else
    // Button 1 + 2 press
    if(readings[0] == 1 && readings[1] == 1 && readings[2] == 0 && (millis() - bTime > 50)) {
      changeBrightness();
      bTime = millis();
    }
    // Button 2 + 3 press
    if(readings[0] == 0 && readings[1] == 1 && readings[2] == 1 && (millis() - vTime > 1000)) {
      changeBirthday();
      vTime = millis();
    }
    // Button 1 + 2 + 3 press
    if(readings[0] == 1 && readings[1] == 1 && readings[2] == 1 && (millis() - sTime > 1000) && (millis() - switchTime > 1000)) {
      maintenanceMode = true;
      FastLED.clear();

      // Clear screen
      for(i = 0; i < numLeds; i++) {
        leds[i] = CRGB:: Black;
      }

      // Set screen colour to white
      hue = 0; sat = 0; val = 255;

      // Clear EEPROM that contains birthdays (max. 20)
      for(i = 0; i < (2*nBirthdays); i++) {
        EEPROM.update(i,0);
      }
      
      Serial.println(F("Initialized maintenance mode!"));
      sTime = millis();
      switchTime = millis();
    }
  }
  
  // Save current readings to new variable for comparison in next loop
  for(i = 0; i < 3; i++) {
    lastReadings[i] = readings[i];
  }
}

// Manual birthday mode controller
void changeBirthday() {
  if(!manualBirthdayMode) {
    manualBirthdayMode = !manualBirthdayMode;
    Serial.println(F("Button 2 + 3 - Birthday mode turned on."));
  } else {
    manualBirthdayMode = !manualBirthdayMode;
    for(i = 0; i < 16; i++) {
      leds[pgm_read_byte(&(birthdayPos[i]))] = CRGB::Black;
    }
    displayTime(hue, sat, val);
    Serial.println(F("Button 2 + 3 - Birthday mode turned off."));
  }
}

// Check if birthday message should be activated based on automatic datekeeping
void checkBirthdays() {
  // Reset birthday boolean
  birthdayMode = false;

  for(i = 0; i < nBirthdays; i++) {
    if(day() == EEPROM.read(i*2) && month() == EEPROM.read(i*2+1)) {
      // If there's any birthday today, enable birthday mode
      birthdayMode = true;
    }
  }
}

// Birthday message code
void birthdays() {
  if((birthdayMode || manualBirthdayMode) && brightness >= 32) {
    static long int waitTime = 0;

    if(millis() - waitTime > 8) {
      for(i = 0; i < 16; i++) {
        leds[pgm_read_byte(&(birthdayPos[i]))] = CHSV(17*i - k, 255, 255);
      }
      k++;
      if(k == 255) {
        k = 0;
      }
      waitTime = millis();
    }
  } else {
    for(i = 0; i < 16; i++) {
      leds[pgm_read_byte(&(birthdayPos[i]))] = CRGB::Black;
    }
  }
}

void displayDigits(uint8_t num) {
  // Print two 5x7 bitmap numbers on the clock screen

  uint8_t numL = (num - (num % 10)) / 10;
  uint8_t numR = num % 10;

  for(i = 0; i < 35; i++) {
    if(pgm_read_byte(&(font5x7[numL][i])) == 1) {
      leds[pgm_read_byte(&(posL[i]))] = CHSV(hue, sat, val);
    }
  }

  for(i = 0; i < 35; i++) {
    if(pgm_read_byte(&(font5x7[numR][i])) == 1) {
      leds[pgm_read_byte(&(posR[i]))] = CHSV(hue, sat, val);
    }
  }
}

void setDateBirthdays() {
  static long int db, db1, db2, db3, db4;

  int readings[3];
  static bool lastReadings[3];
  
  static int debounceTime = 200;
  
  static uint8_t dayVal = 1;
  static uint8_t monVal = 1;

  static bool settingDay = true;
  static bool settingBirthday = false;

  static uint8_t nBirthday = 0;

  // Get and process readings
  if(analogRead(buttonPins[0]) < 100) {readings[0] = true;} else {readings[0] = false;}
  if(analogRead(buttonPins[1]) < 100) {readings[1] = true;} else {readings[1] = false;}
  if(analogRead(buttonPins[2]) < 100) {readings[2] = true;} else {readings[2] = false;}

  // Check if button state has changed w.r.t. last loop
  for(i = 0; i < 3; i++) {
    if(readings[i] != lastReadings[i]) {
      // Register time at which buttons were pressed
      db = millis();
    }
  }

  // Button logic
  if(millis() - db > debounceTime) {
    // Button 1 press
    if(readings[0] == 1 && readings[1] == 0 && readings[2] == 0 && (millis() - db1 > 500)) {
      if(!settingDay) {
        if(!settingBirthday) {
          // Write date value to clock
          rtc.adjust(DateTime(year(), monVal, dayVal, hour(), minute(), second()));
          
          // Reset date indicators
          dayVal = 1;
          monVal = 1;

          // Now start saving birthdays to EEPROM
          settingBirthday = true;

          // Confirm new date by printing it to console
          DateTime now = rtc.now();
          Serial.print("New date written to RTC: "); Serial.print(year()); Serial.print("-"); Serial.print(month()); Serial.print("-"); Serial.print(day()); Serial.print(" "); Serial.print(hour()); Serial.print(":"); Serial.print(minute()); Serial.print(":"); Serial.print(second()); Serial.println(".");
        } else {
          // Write birthday pair (day + month) to EEPROM
          EEPROM.update(nBirthday*2, dayVal);
          EEPROM.update(nBirthday*2+1, monVal);

          // Confirm birthday by printing it to console
          Serial.print("New birthday saved (number "); Serial.print(nBirthday); Serial.print("). Date: "); Serial.print(dayVal); Serial.print("-"); Serial.print(monVal); Serial.println(".");

          // Reset date indicators
          dayVal = 1;
          monVal = 1;

          // Increase the birthday counter if there is sufficient room
          if(nBirthday < 20) {
            nBirthday++;
          } else {
            // Otherwise, quit maintenance mode and resume normal operation
            for(i = 0; i < numLeds; i++) {
              leds[i] = CRGB::Black;
            }

            // Retrieve old hue, sat and val from EEPROM
            hue = pgm_read_byte(&(colours[colourIndex][0]));
            sat = pgm_read_byte(&(colours[colourIndex][1]));
            val = pgm_read_byte(&(colours[colourIndex][2]));
            
            displayTime(hue, sat, val);

            // Reset day and month indicators
            dayVal = 1;
            monVal = 1;
            
            maintenanceMode = false;
            checkBirthdays();
          }
        }
      }
      
      // Flip the current setting
      settingDay = !settingDay;
      
      db1 = millis();
    } else
    // Button 2 press
    if(readings[0] == 0 && readings[1] == 1 && readings[2] == 0 && (millis() - db2 > 500)) {
      if(settingDay) {
        if(dayVal < 31) {
          dayVal++;
        } else {
          dayVal = 1;
        }
      } else {
        if(monVal < 12) {
          monVal++;
        } else {
          monVal = 1;
        }
      }
      db2 = millis();
    } else
    // Button 3 press
    if(readings[0] == 0 && readings[1] == 0 && readings[2] == 1 && (millis() - db3 > 500)) {
      if(settingDay) {
        if(dayVal > 1) {
          dayVal--;
        } else {
          dayVal = 31;
        }
      } else {
        if(monVal > 1) {
          monVal--;
        } else {
          monVal = 12;
        }
      }
      db3 = millis();
    }
    // Button 1 + 2 + 3 press
    if(readings[0] == 1 && readings[1] == 1 && readings[2] == 1 && (millis() - db4 > 500) && (millis() - switchTime > 1000)) {
      // Quit maintenance mode and resume normal operation
      for(i = 0; i < numLeds; i++) {
        leds[i] = CRGB::Black;
      }

      // Retrieve old hue, sat and val from EEPROM
      hue = pgm_read_byte(&(colours[colourIndex][0]));
      sat = pgm_read_byte(&(colours[colourIndex][1]));
      val = pgm_read_byte(&(colours[colourIndex][2]));
      
      displayTime(hue, sat, val);

      // Reset day and month indicators
      dayVal = 1;
      monVal = 1;

      Serial.println("Maintenance mode disabled!");
      
      maintenanceMode = false;
      checkBirthdays();
      
      db4 = millis();
      switchTime = millis();
    }
  }

  // Clear original led index
  if(maintenanceMode) {
    for(i = 0; i < numLeds; i++) {
      leds[i] = CRGB::Black;
    }

    if(settingDay) {
      displayDigits(dayVal);
    } else {
      displayDigits(monVal);
    }
  }

  // Save current readings to new variable for comparison in next loop
  for(i = 0; i < 3; i++) {
    lastReadings[i] = readings[i];
  }
}
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

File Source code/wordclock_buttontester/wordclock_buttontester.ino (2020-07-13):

/* wordclock_buttontester.ino
 * A simple piece of code to test the buttons. Feedback is provided through serial output.
 * By Willem Pennings
 */

long buttonTime = 0;
int interval = 1000;

int colorPin = A1;
int incrementPin = A2;
int decrementPin = A3;

int a, b, c;

void setup() {
  Serial.begin(115200);

  pinMode(incrementPin, INPUT);
  pinMode(decrementPin, INPUT);
  pinMode(colorPin, INPUT);
}

void loop() {
  a = analogRead(colorPin);
  b = analogRead(incrementPin);
  c = analogRead(decrementPin);

  Serial.print(a); Serial.print("\t");
  Serial.print(b); Serial.print("\t");
  Serial.println(c);
}

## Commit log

2018-07-04 Firmware: add variable brightness feature; Mechanical: update lasercutting plans
    [clocksquared_frontplate_standard.dwg, clocksquared_grid.dwg, clocksquared_lasercutting_laserbeest.dwg]
2019-06-24 Updated lasercutter files and source code
    [clocksquared_frontplate_standard.dwg, letter layout - Dutch.xlsx, letter layout - English.xlsx]
2019-07-30 Add electronics schematic
2019-07-30 remove redundant design files
    [grid_sheet.prt, grid_sheet.stp, grid_sheet_dwg.prt]
2020-02-04 Restructured source code, improved performance, added lots of functionality
    [0-9 bitmap font.xlsx]
2020-07-13 Major schematic update (for WS2813B LEDs), minor code adjustments
2020-07-13 Major upgrade of electrical system (WS2813B LEDs)
